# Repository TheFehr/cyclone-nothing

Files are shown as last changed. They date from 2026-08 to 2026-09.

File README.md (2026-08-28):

# cyclone-nothing

Parametric 3D-printable phone holder that mounts a Nothing Phone 2 onto a GameSir Cyclone 2 controller — connector plate, diagonal arm, print-in-place swivel pivot, and a self-centering screw-adjustable clamp.

**[Open the live customizer / STL export →](https://thefehr.github.io/cyclone-nothing/)**
**[Read the assembly guide →](https://thefehr.github.io/cyclone-nothing/assembly_guide.html)**

## What it does

- Snap-fit connector plate slides into the controller's own USB-C accessory port — no glue, no screws, reverse-engineered from a real controller.
- A tilted arm carries a print-in-place swivel pivot, so the clamp rotates 90° between portrait (handheld console emulation) and landscape (x64 emulation — also works for PC streaming) orientations without removing the phone.
- The clamp is a screw-adjustable, car-mount-style claw grip on the phone's short edges — screen and back stay fully exposed. A dual-handed printed leadscrew draws both claws in together and keeps the phone centered at any width.
- **No metal anywhere.** Every joint is either a real printed helical thread or a plain friction-fit pin cut from your own printer filament, glued in place. No screws, nuts, or hardware to source.

## Print + assemble

Nine independent print jobs, no combined prints, no captured/impossible-to-assemble joints — see the [assembly guide](https://thefehr.github.io/cyclone-nothing/assembly_guide.html) for the parts list, hardware (4 filament pins + CA glue), and the exact build order (some joints can only close in one sequence).

Verified STL exports for the current design live in [`stl/`](stl/); the [live customizer](https://thefehr.github.io/cyclone-nothing/) lets you tweak any dimension (screw diameter, rail length, clamp reach, pivot tilt, etc.) and export fresh STLs for your own printer/tolerances.

## Repo layout

- `phone_holder.scad` — the parametric design, annotated with OpenSCAD Customizer comments (drives the live web form automatically).
- `lib/threads.scad` — [rcolyer/threads-scad](https://github.com/rcolyer/threads-scad) (CC0), used for the printed leadscrew/nut threads.
- `stl/` — current verified STL export of all 9 parts.
- `reference/` — measurements/reference meshes the connector plate was reverse-engineered from.
- `index.html` / `worker-shim.js` — the live in-browser preview, built on [openscad-customizer-web](https://github.com/TheFehr/openscad-customizer-web).
- `assembly_guide.html` — step-by-step build guide.

## License

[CC BY 4.0](https://creativecommons.org/licenses/by/4.0/)

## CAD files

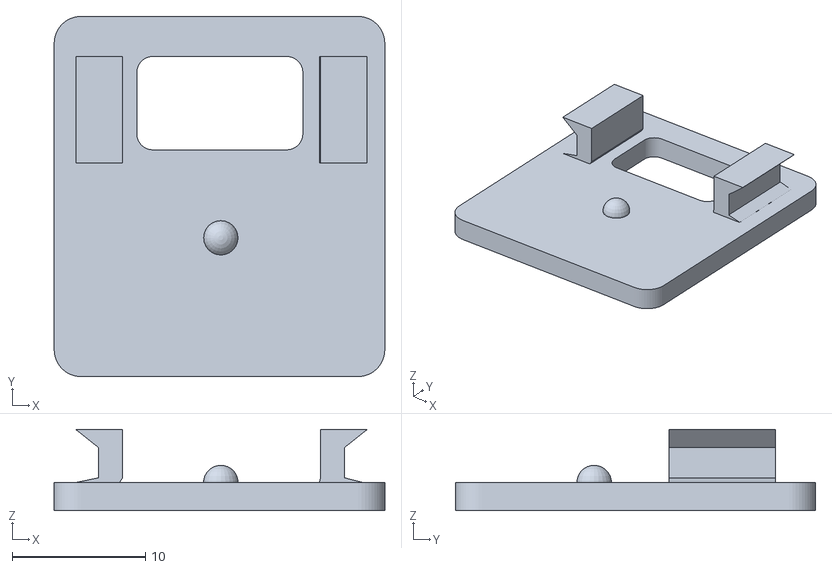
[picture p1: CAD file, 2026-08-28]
connector_plate_4mm.stl
24.8 x 27.0 x 6.11

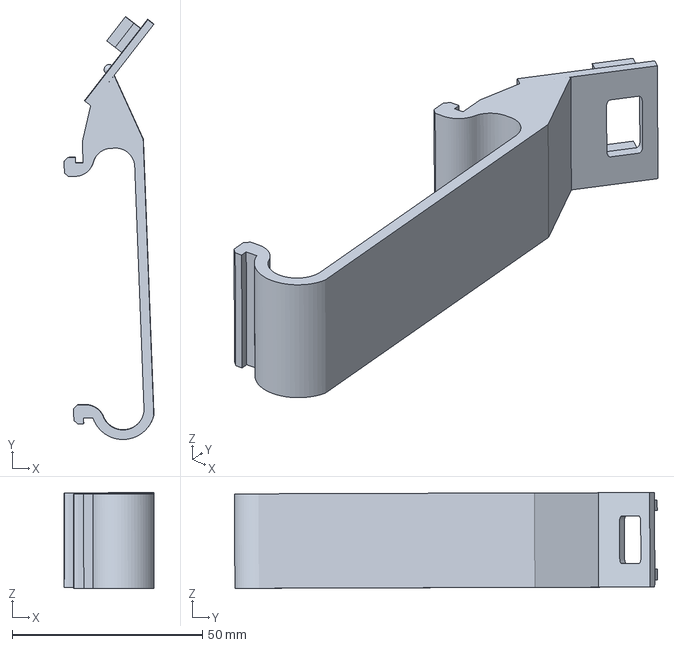
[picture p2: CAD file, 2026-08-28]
reference/Gamesir_iPhone_XS_cover_support.3mf
23.6 x 111.0 x 25.2 mm

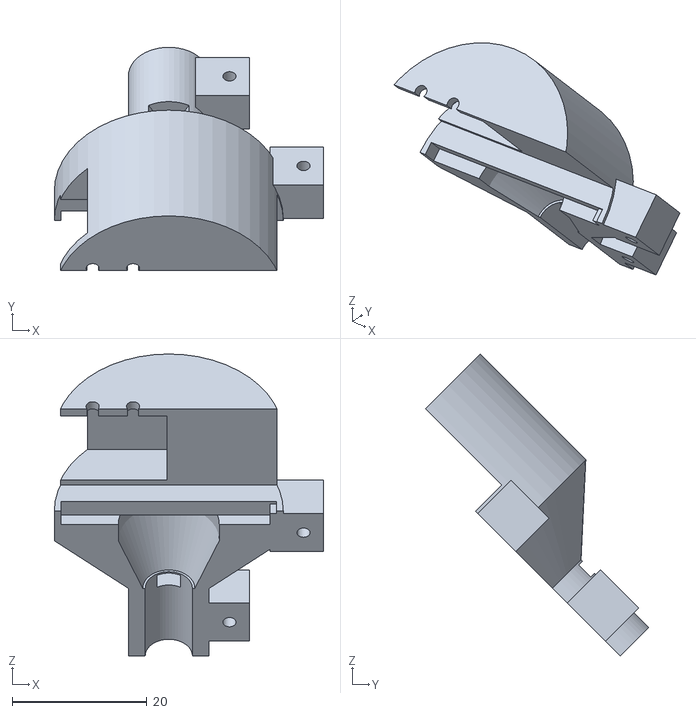
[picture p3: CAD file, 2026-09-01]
stl/collar_bottom.stl
40.0 x 33.2 x 44.8

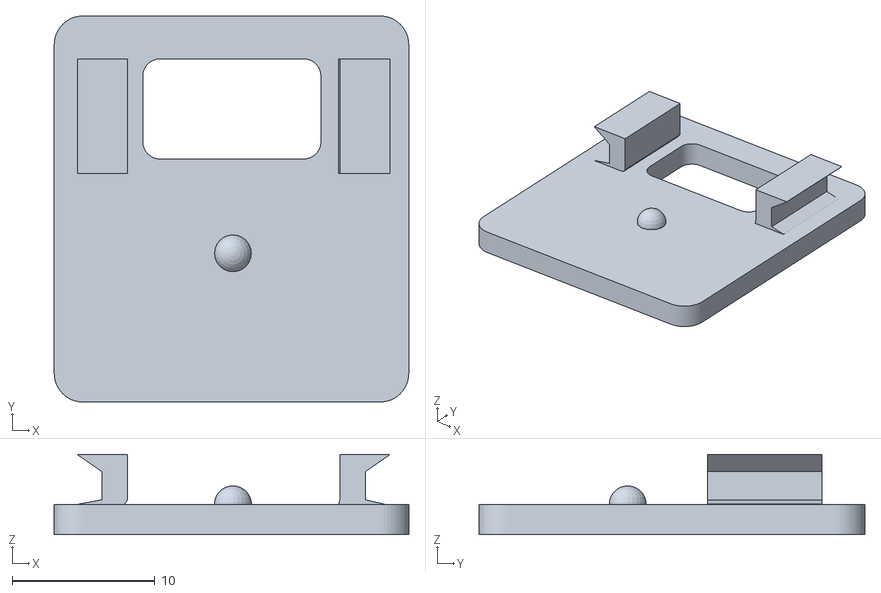
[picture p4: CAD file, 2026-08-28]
connector_plate.stl
24.8 x 27.0 x 5.61

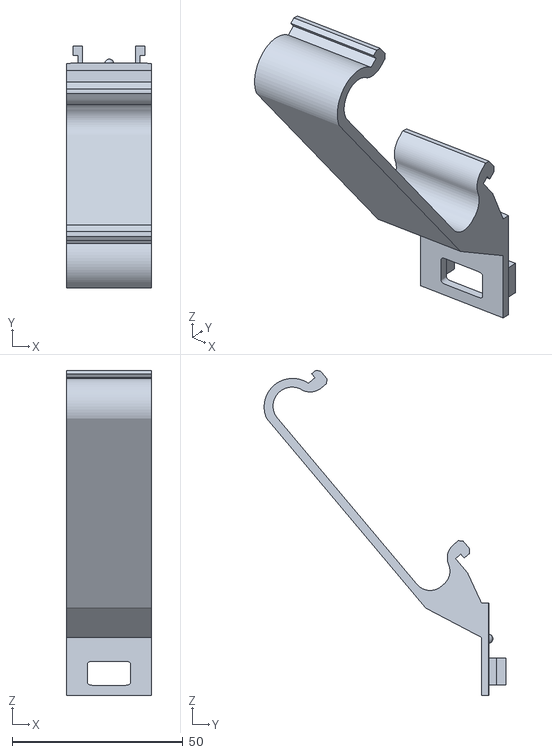
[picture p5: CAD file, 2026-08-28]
reference/iphone_xs_cover_support.stl
24.8 x 70.7 x 95.1

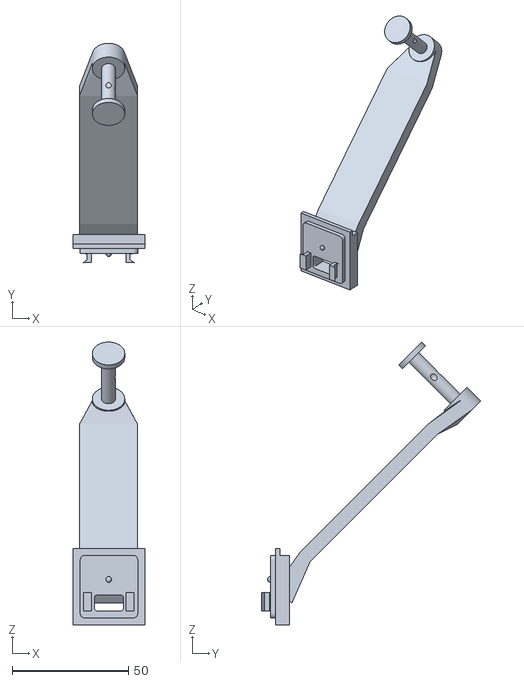
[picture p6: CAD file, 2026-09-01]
stl/base.stl
30.8 x 94.5 x 121.9

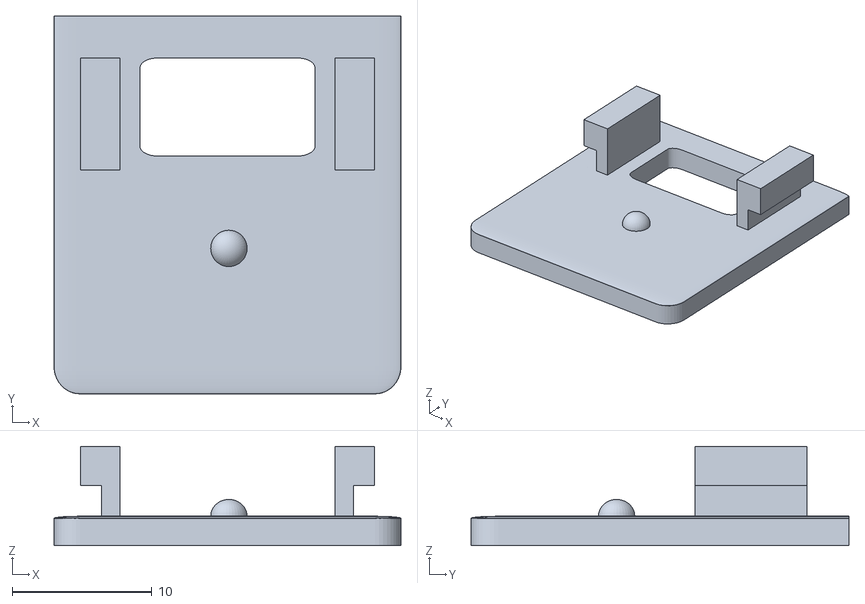
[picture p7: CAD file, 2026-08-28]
reference/connector_only.stl
24.8 x 27.0 x 7.11

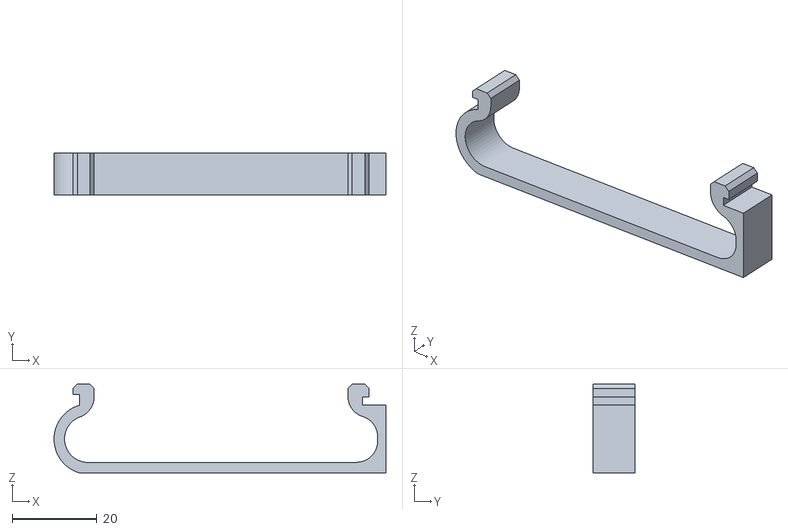
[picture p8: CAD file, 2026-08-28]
reference/size_check_thin.stl
78.5 x 10.0 x 21.0

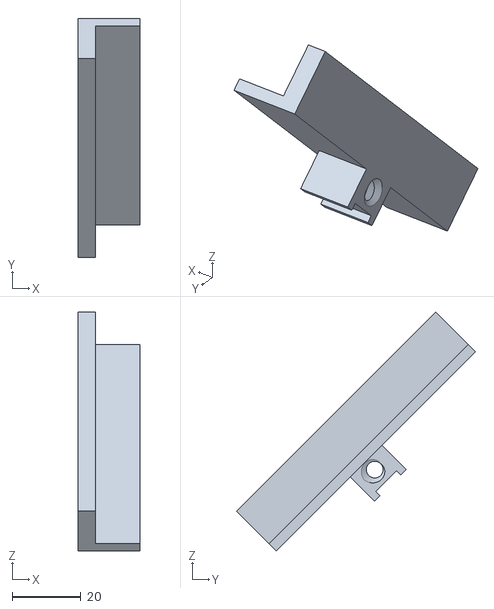
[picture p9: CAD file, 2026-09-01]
stl/clamp_claw_left.stl
18.0 x 69.6 x 69.6

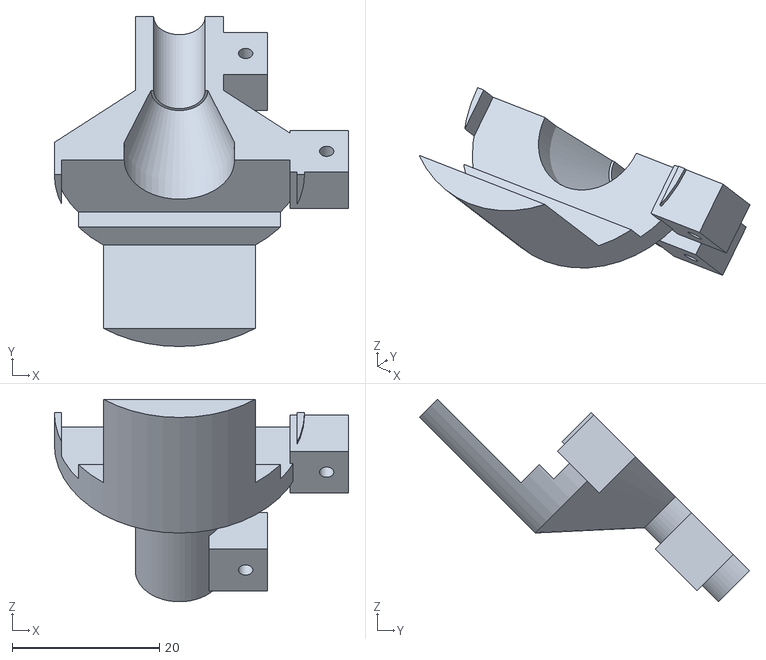
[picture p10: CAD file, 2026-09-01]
stl/collar_top.stl
40.0 x 44.8 x 27.5

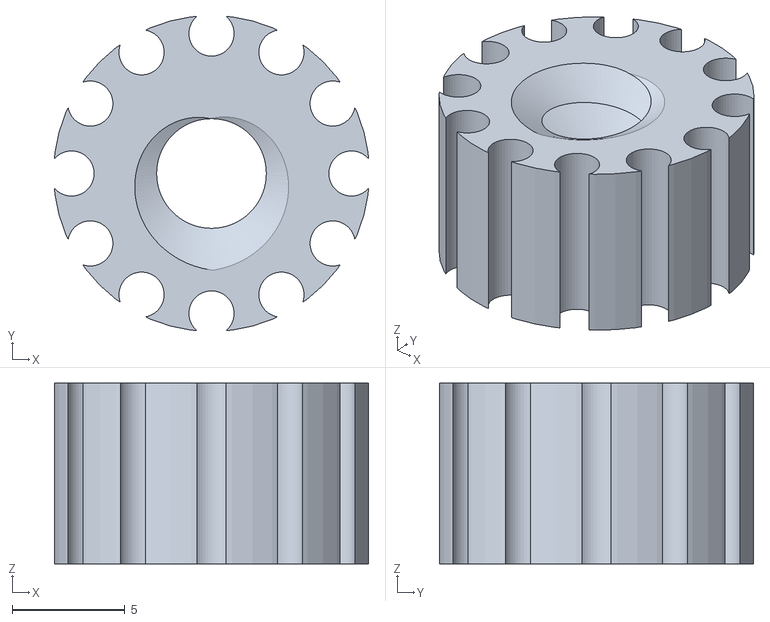
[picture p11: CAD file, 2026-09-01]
stl/knob.stl
13.9 x 13.9 x 8.00

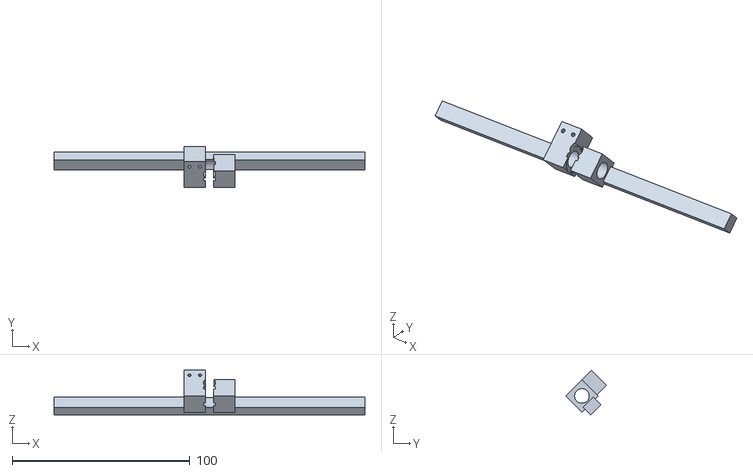
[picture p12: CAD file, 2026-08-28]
stl/clamp_center.stl
175.0 x 23.0 x 25.1

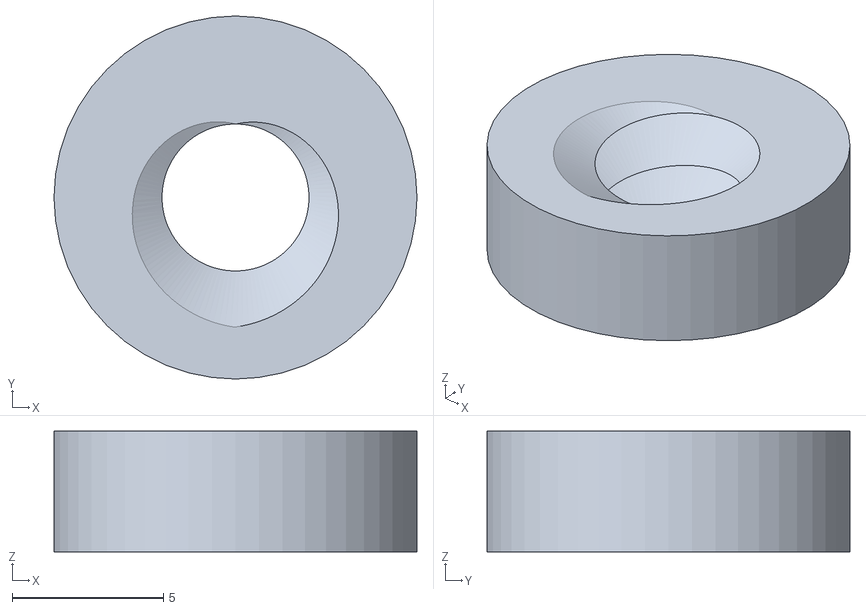
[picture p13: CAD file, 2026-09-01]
stl/flange_nut.stl
12.0 x 12.0 x 4.00

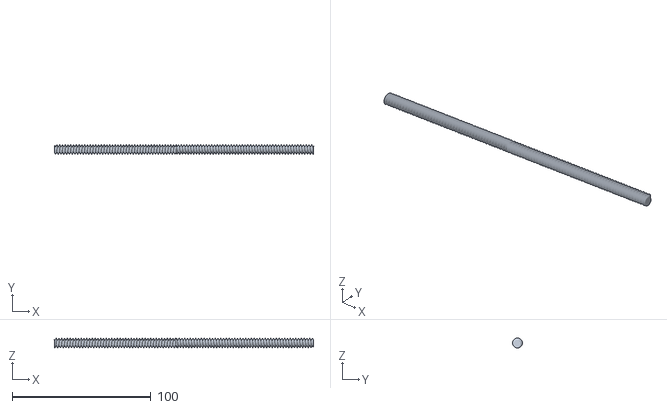
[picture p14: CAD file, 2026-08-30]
stl/screw.stl
186.5 x 7.10 x 7.10

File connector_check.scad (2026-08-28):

bulk_margin=3; bulk_depth=6;
module connector() { rotate([90,0,0]) translate([5.3,-1,2.55]) import("reference/connector_only.stl"); }
module usb_slot_clearance() { translate([-7.5,-3.55,-17.9]) cube([12.7, 3.55+bulk_depth+10, 8.6]); }
module connector_bulk() { difference() { translate([-12.4-bulk_margin, 3.55, -27-bulk_margin]) cube([24.8+2*bulk_margin, bulk_depth, 27+2*bulk_margin]); usb_slot_clearance(); } }
connector();
color("orange",0.6) connector_bulk();

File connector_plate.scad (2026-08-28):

// Standalone connector plate -- the piece that slides into the GameSir
// Cyclone-family controller's mount. Rebuilt natively in OpenSCAD from
// measurements taken off a real, watertight reference mesh
// (reference/connector_only.stl), rather than imported as an opaque mesh,
// so it can be freely extended/modified later without guessing what's
// safe to touch.
//
// Tab-clip size/position/profile, the plate footprint, and the USB-C slot
// are measured to match the reference mesh (these mate with real
// hardware); the corner fillets and the small alignment nub are close
// visual approximations, not exact -- they carry no mechanical function.
//
// The tabs are NOT plain posts -- they're snap-fit barbs: a base flush
// with the plate surface (no riser gap), blending immediately into a
// constant-width neck that slides through the controller's narrow lower
// opening, then a head that flares out in the wider pocket beyond.
//
// Print flat as-is: bottom face on the bed, tabs pointing up, no supports.

plate_w = 24.8; plate_l = 27; plate_t = 2.11; plate_corner_r = 2;
tab_y = -10.0; tab_l = 8.0;

// Depth budget: base to head tip, starting flush at the plate surface
// (Z = plate_top_z) -- confirmed by hand-sketch (option D) that the neck
// must start with zero gap/recess below it, not sit atop a tall separate
// base riser like the first cut did.
plate_top_z = -4.0; plate_bottom_z = -6.11;
tab_z0 = plate_top_z;
// Depth budget arrived at through printed test-fit iteration (8mm guessed
// -> 4.5mm measured -> 3.5mm, still ~1mm too deep -> 4mm confirmed best
// via an A/B print test against a 3.5mm variant).
tab_base_blend_h = 0.34; // short transition from the wide base footprint to the neck, right at the plate surface
tab_z_neck_top = tab_z0 + 2.63; // neck runs most of the depth budget
tab_z1 = tab_z0 + 4.0; // full measured depth budget, head tip

// Neck inner-gap measured directly off the real controller with calipers
// (14.85mm, facing edges) -- center-to-center = 14.85 + neck_w = 16.65mm.
// base_x (the structural bond to the plate) stays at the reference mesh's
// original position; only neck/head -- the part that actually engages the
// controller -- are repositioned, preserving the previous midpoint.
tab1_base_x = -16.0; tab1_neck_x = -14.375;
tab2_base_x = 2.2; tab2_neck_x = 2.275;
// Each head flares away from the slot (not toward it) to avoid colliding
// with it now that the necks sit closer to center: tab1 keeps its neck's
// RIGHT edge flush and widens left; tab2 keeps its neck's LEFT edge flush
// and widens right.
tab1_head_x = tab1_neck_x - 1.7; // = tab1_neck_x + tab_neck_w - tab_head_w, right-edge flush
tab2_head_x = tab2_neck_x; // left-edge flush

// neck_w capped just under 1.85mm (the real controller's lower-opening
// width, measured) since the neck has to slide through it; head_w capped
// just under 3.6mm (measured max for the wider pocket beyond) -- both
// maximized within those limits for retention strength.
tab_base_w = 3.2; tab_neck_w = 1.8; tab_head_w = 3.5;
slot_x = -11.5; slot_y = -9; slot_w = 12.45; slot_h = 7; slot_corner_r = 1.2;
nub_x = -5.2; nub_y = -15.6; nub_r = 1.3;

$fn = 48;

module tab_clip(base_x, neck_x, head_x) {
    hull() {
        translate([base_x, tab_y, tab_z0]) cube([tab_base_w, tab_l, 0.02]);
        translate([neck_x, tab_y, tab_z0 + tab_base_blend_h]) cube([tab_neck_w, tab_l, 0.02]);
    }
    translate([neck_x, tab_y, tab_z0 + tab_base_blend_h])
        cube([tab_neck_w, tab_l, tab_z_neck_top - (tab_z0 + tab_base_blend_h)]);
    hull() {
        translate([neck_x, tab_y, tab_z_neck_top]) cube([tab_neck_w, tab_l, 0.02]);
        translate([head_x, tab_y, tab_z1 - 0.02]) cube([tab_head_w, tab_l, 0.02]);
    }
}

module connector_plate_native() {
    difference() {
        union() {
            translate([-17.7, -26, plate_bottom_z])
                linear_extrude(plate_t)
                    hull()
                        for (x = [plate_corner_r, plate_w - plate_corner_r])
                            for (y = [plate_corner_r, plate_l - plate_corner_r])
                                translate([x, y]) circle(r = plate_corner_r);
            tab_clip(tab1_base_x, tab1_neck_x, tab1_head_x);
            tab_clip(tab2_base_x, tab2_neck_x, tab2_head_x);
            translate([nub_x, nub_y, plate_top_z]) sphere(r = nub_r, $fn = 24);
        }
        translate([0, 0, plate_bottom_z - 1])
            linear_extrude(plate_t + 2)
                hull()
                    for (x = [slot_x + slot_corner_r, slot_x + slot_w - slot_corner_r])
                        for (y = [slot_y + slot_corner_r, slot_y + slot_h - slot_corner_r])
                            translate([x, y]) circle(r = slot_corner_r);
    }
}

connector_plate_native();

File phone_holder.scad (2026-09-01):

// Phone holder arm for a GameSir Cyclone-family controller + Nothing Phone 2.
//
// Layout: [connector, bulked for strength, USB-C slot left open] --diagonal
// arm (angle customizable)--> [print-in-place rotating pivot] --> [clamp
// running along the phone's LONG edge].
//
// The pivot's rotation axis is perpendicular to the phone's flat face, so
// spinning the clamp end 90 degrees swaps portrait (DS emulation) <->
// landscape (PC emulation) while the phone stays flat-facing the same way.
// It's a single printed-in-place pin+collar (no bolt/nut, no second print)
// -- print with the model rotated so Y is vertical on the bed, so the
// pin/collar layers form clean concentric circles instead of needing to
// bridge the clearance gap.
//
// Base geometry (connector_only.stl) is reverse-engineered from a
// Thingiverse remix (thing:6765266, nikopla / HaraldVI, CC BY), kept
// byte-for-byte since it has to mate with real hardware.
//
// The phone clamp is screw-adjustable, car/bike-mount claw style: a small
// hook claw at each end of a rail grips only the phone's short top/bottom
// edges -- screen and back stay fully exposed. One claw is fixed, the
// other rides a printed leadscrew (real threads, rcolyer/threads-scad,
// CC0) that runs along the phone's long axis -- no metal hardware
// anywhere in this design.

use <lib/threads.scad>

/* [Render] */

// Which piece to show/export. "full" is an assembled preview only -- the
// pivot pin/collar, the two claws, and the leadscrew are separate, unfused
// bodies (by design -- print-in-place pivot, screw-adjustable clamp), so
// it isn't watertight/printable as a single part.
render_part = "connector"; // [connector:Connector plate only — reference only; base.stl already includes it,base:Connector + arm + pivot pin (print this),clamp_center:Rail + both bearing bosses — no collar (print this),collar_top:Pivot collar top half — screws onto collar_bottom around the pin (print this),collar_bottom:Pivot collar bottom half (print this),flange_nut:Screw retention flange — threads onto the screw's center then glued (print this),TEST_flange_fit:Quick fit test — flange_nut + a short thread stub — print this first to check thread_tolerance before the full screw,TEST_claw_fit:Quick fit test — full-length claw thread bore (no lip/wall) + a matching stub — print this first to check thread_tolerance before a full claw,TEST_pivot_detent:Quick fit test — short shaft + short tube with the pivot detent — print this first to tune the click force before a full pin/collar,clamp_claw_right:Right claw — right-hand thread (print this),clamp_claw_left:Left claw — left-hand thread (print this),screw:Dual-thread leadscrew — no flange or knob (print this),knob:Turning knob — threads onto the screw's tip then glued (print this),full:Full assembly (preview only)]

/* [Connector] */

// Extra material added around the connector base for strength (the USB-C
// slot is always kept clear regardless of this value)
bulk_margin = 3; // [0:0.5:8]

// How far the bulk pad extends outward before the arm begins
bulk_depth = 6; // [2:0.5:15]

/* [Arm] */

// Tilt of the arm away from straight-up, toward the phone
arm_angle = 45; // [0:1:60]

// Arm length along that diagonal -- driven by DS/portrait-mode clearance,
// not looks. Short-edge grip (claws on the phone's 162mm length, naturally
// symmetric on X) plus the now-symmetric width grip (Y) gives a worst-case
// corner at sqrt(81^2 + 38.2^2) = ~89.6mm from the axis. 110 gives ~96.4mm
// of clearance against the reinforced connector pad (verified via the
// same closest-point-to-bbox check used throughout), a margin over the
// 89.6mm minimum.
arm_length = 110; // [20:1:220]

// Cross-section at the pivot end
arm_thickness = 6; // [2:0.5:12]
arm_width = 25; // [20:0.5:30]

// Cross-section at the connector end -- thicker on purpose: this is a
// cantilever fixed at the connector and loaded at the pivot end, so
// bending stress is highest right here, not at the tip
arm_base_thickness = 10; // [4:0.5:18]
arm_base_width = 24.8; // [20:0.5:30]

// How far the gusset at each end blends into the standard arm
// cross-section before running the rest of arm_length at full thickness
arm_gusset_len = 16; // [5:1:40]

/* [Pivot] */

// Print-in-place: rotation axis runs perpendicular to the phone's face.
// Print with this axis vertical on the bed for a clean result.
pivot_shaft_dia = 6; // [4:0.5:12]
pivot_shaft_len = 30; // [16:1:60]
pivot_flange_dia = 14; // [8:0.5:24]
pivot_flange_h = 2.4; // [1.2:0.2:5]
pivot_collar_dia = 12; // [8:0.5:22]
pivot_clearance = 0.5; // [0.2:0.05:1]

// Detent so the pivot actually HOLDS portrait/landscape instead of free-
// spinning under the phone's own weight (real print feedback, 2026-09-01
// -- pivot_clearance above is a pure running-clearance fit, nothing in
// this design ever created any resistance at all). A single flexible tab
// on the collar's own bearing tube, with a small bump on its inner face,
// riding on the shaft -- pushed outward (flexed) everywhere except at two
// shallow dimples cut into the shaft 90deg apart, where it relaxes and
// "clicks" in. No fixed relationship between the collar's own rotation
// reference and either dimple is needed -- the collar isn't keyed to the
// pin at assembly (you close the clamshell around the shaft at whatever
// starting angle), so both detent positions are reached identically by a
// 90deg swing regardless of where you started, the same swing that
// already swaps portrait/landscape.
//
// UNTESTED. FDM cantilever spring force from CAD alone is notoriously
// unreliable -- wall thickness accuracy, layer adhesion direction, and
// material all move it a lot. Print TEST_pivot_detent (a short shaft-and-
// tab coupon) and adjust detent_bump_h/detent_tab_wall against it before
// committing to a full pin+collar reprint.
detent_bump_h = 0.6; // [0.1:0.05:0.8] how far the tab's rest position reaches past the shaft's plain surface -- also the dimples' depth. Bumped from 0.4 (2026-09-02): real TEST_pivot_detent print had too little resistance/held too loosely at 0.4. Re-test with the coupon again before committing to a full pin+collar reprint.
detent_tab_wall = 1.2; // [0.6:0.1:2.5] radial thickness of the flexible tab -- thinner flexes more easily but risks snapping instead of springing
detent_tab_arc = 60; // [30:5:100] degrees of arc the tab spans -- its flex length

// How far the collar extends PAST the shaft's far flange before the rail/
// claw assembly attaches, measured from where the flange-clearing cap
// ends. The claws need to reach all the way to the true axis line (X=0,
// Y=0) to grip the phone centered on BOTH axes -- but at the shaft's own
// depth, that exact spot is solid collar material. This pushes the
// attachment point further along the axis (further from the connector,
// "toward the user") into empty space where nothing blocks X=0,Y=0.
//
// Trimmed down from an earlier, more generous 30 once a structural check
// showed the extra rod thickness wasn't needed (bending stress from the
// phone's static weight is ~25x under typical FDM strength regardless).
// But it can't go BELOW ~20.2: at that point the rail creeps back far
// enough to overlap the FAR FLANGE's own Z-range (a separate constraint
// from the rod-length one) -- caught via the full rotation-sweep check,
// which showed a constant collision at every angle (a dead giveaway it
// was a static Z-overlap, not an actual rotational sweep problem). 24
// keeps a few mm of margin over that floor.
pivot_standoff = 24; // [21:1:60]

// Extra tilt of the pivot axis, on top of the base -90 degrees (which
// would face the clamp straight back down the arm at the controller).
// Needed for two reasons: (1) so the phone's screen faces the user
// instead of pointing down at their hands on the controller, and (2) so
// the clamp/rail clears the arm and controller body as it swings between
// DS/portrait and PC/landscape instead of crashing into them mid-rotation.
// ~135 was confirmed correct via a render sweep (0/45/90/135/180/-45)
// against where the screen should face -- re-verify with a render if the
// arm_angle or connector orientation changes materially.
pivot_tilt = 135; // [0:1:180]

/* [Clamp] */

// Total rail length, along the phone's LONG axis -- needs to cover the
// phone's height (162mm) plus adjustment travel
rail_length = 175; // [100:1:250]

// Distance from the rail's center (X=0, where the pivot attaches) to each
// claw. Both claws sit at +-claw_offset -- symmetric, so the phone stays
// centered on the pivot on the LENGTH axis at any grip width. Default
// targets a ~162mm grip span to match the Nothing Phone 2's height.
claw_offset = 81; // [20:1:85]

// Width of each claw along the rail axis
claw_width = 18; // [10:1:30]
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

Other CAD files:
stl/clamp_claw_right.stl

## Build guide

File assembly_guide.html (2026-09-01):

# Pivot Mount Assembly

Nine printed parts. No metal anywhere — every joint is either a printed thread or a friction-fit pin cut from the same filament you printed with, plus CA glue. Follow the sequence — some joints can only be closed in this order.

cyclone‑nothing / phone_holder.scad
rev 2026‑08‑30
9 parts · 4 filament pins · 0 metal

## 01Parts manifest

Print all nine before starting assembly. Each is a standalone job — nothing here needs to be printed in the same session as anything else.

Base

Base

base.stl

Connector, arm, and the fixed pivot pin — one solid piece.

qty 1

Rail with both bearing bosses

Rail & bosses

clamp_center.stl

The long rail with both bearing bosses fixed in place, plus the rod-connect shelf.

qty 1

Collar top half

Collar — top half

collar_top.stl

Clamshell half. Closes around the pin from above.

qty 1

Collar bottom half

Collar — bottom half

collar_bottom.stl

Carries the full standoff rod and its two rail pin holes.

qty 1

Flange nut

Flange nut

flange_nut.stl

Threads onto the leadscrew's own thread inside the gap, then glued. Captures the screw axially so it can spin but not slide.

qty 1

Leadscrew

Leadscrew

screw.stl

Right- and left-hand thread from center; right-hand thread runs all the way to the tip.

qty 1

Knob

Knob

knob.stl

Threads onto the screw's tip, then glued — last part installed.

qty 1

Right claw

Claw — right

clamp_claw_right.stl

Right-hand thread bore. Threads onto the +X half.

qty 1

Left claw

Claw — left

clamp_claw_left.stl

Mirrored thread bore. Threads onto the −X half.

qty 1

Hardware 4× ~15mm length of your own 1.75mm printer filament, cut with flush cutters, used as friction-fit pins · small drop of CA or epoxy at the flange nut, both pin joints, and the knob · no metal anywhere in this build

## 02Build sequence

Two sub-assemblies come together independently, then join at the very end. Steps 1–3 build the clamp; step 4 builds the pivot; steps 5–6 join them and finish.

Flange nut held in the open gap between the two bosses, no screw yet

1

### Start the leadscrew into the near boss

clamp_center.stl + screw.stl

The leadscrew's two ends aren't interchangeable here: flange_nut only threads onto the left-hand-thread end. Feed that end into its matching boss and turn it in just until a little thread pokes through into the open gap. (The other end is right-hand thread all the way to its tip — wrong handedness for this nut, so it never comes into it.)

Leadscrew threaded all the way through the flange nut and both bosses

2

### Thread the flange nut on as you turn it in

+ flange_nut.stl · CA glue

Hold flange_nut right at the gap where the thread is just starting to emerge — it catches immediately, since that thread is already the same handedness as the nut. Keep turning the leadscrew in the same direction: the nut climbs onto it and seats itself within the gap after a few turns, then just rides there while you keep feeding the rest of the leadscrew through — through the nut's own bore and on through the far boss — until it's fully seated, parallel with the rail underneath. Run a small bead of CA glue around the nut once everything's seated so it can't work itself loose.

Check: once the glue sets, spin the leadscrew by hand. It should turn smoothly with no drag or axial play before you continue. If feeding the last stretch through the nut feels tight or binds, stop and let us know — that specific step hasn't been physically confirmed yet.

Both claws threaded onto the screw

3

### Thread on the claws

+ clamp_claw_right.stl + clamp_claw_left.stl

Rotate clamp_claw_right onto the screw's +X (right-hand thread) end, and clamp_claw_left onto the −X (left-hand thread) end, threading each in from the tip toward the center. Because the threads are opposite-handed, turning the leadscrew one way draws both claws in together and centers the grip automatically.

Base pin with both collar halves closing around it

4

### Close the collar around the pin

base.stl + collar_top.stl + collar_bottom.stl · 2 filament pins

Set base's pin down and bring collar_top and collar_bottom together around it — the two halves meet along the pin's own axis. Push a ~15mm length of 1.75mm filament through each of the two tabs' aligned holes to close the clamshell, and add a small drop of CA glue at each so they can't work loose. Confirm the collar rotates with a steady, even resistance the whole way around, and clicks noticeably at two points 90° apart (the detent) — not free-spinning, and not so stiff you can't turn it by hand. It's this resistance that holds the phone in portrait/landscape instead of it falling under its own weight.

Collar and clamp sub-assembly joined

5

### Join the two sub‑assemblies

step 4 result + step 3 result · the last 2 filament pins

Push your last 2 filament pins into the two holes at collar_bottom's standoff rod tip, leaving them protruding slightly. Bring the clamp sub‑assembly (from step 3) up to meet the rod, aligning the connect shelf on clamp_center so the protruding pin ends slide into its matching holes as the two faces come together — like a standard dowel joint. Add a small drop of CA glue at each pin once seated. This is the joint that makes the rail and claws actually rotate with the collar — everything downstream of it now turns together as one unit.

Finished assembly with knob and phone outline

6

### Thread on the knob

+ knob.stl

Thread knob onto the screw's tip (right-hand thread, same direction as the right claw) and turn it until it seats flush against the right claw's outward wall. Put a small drop of CA or epoxy at the seam once seated — the thread engagement carries the turning torque, the glue just keeps it from working loose. Give the glue its full cure time before using the knob to adjust the clamp.

Done: the phone's short edges seat in the two claws, centered on the true pivot axis in both length and width. Turn the knob to open or close the grip; rotate the whole clamp 90° on the collar to swap portrait and landscape.

cyclone‑nothing phone_holder.scad

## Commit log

2026-08-28 Initial commit: phone_holder pivot mount design, STLs, and assembly guide
    Nine-part, fully modular, metal-free design (printed threads + 1.75mm
    filament friction-fit pins) for mounting a Nothing Phone 2 onto a
    GameSir Cyclone 2 controller. Includes the parametric OpenSCAD source,
    current verified STL exports, and a step-by-step HTML assembly guide.
    [Gamesir_iPhone_XS_cover_support.3mf, base.stl, clamp_center.stl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]
2026-08-28 Set up GitHub Pages: live customizer + assembly guide
    Matches the pattern used by earpad-adapter and openscad-customizer-web
    itself: preview.html -> index.html (served at the Pages root), a
    minimal actions/deploy-pages workflow, .nojekyll, and .gitattributes
    for sane diffs on the .scad source. Cross-linked index.html and
    assembly_guide.html so either page reaches the other. Added a README
    pointing at both published pages.
2026-08-28 Fix connector's misleading print label, add pregen STL fast-path
    The connector-only render_part was labeled "(print this)" even though
    base.stl already includes it -- printing it separately is redundant,
    not a real 9th part. Clarified the Customizer dropdown label.
    index.html now uses openscad-customizer-web's lower-level building
    blocks (parseCustomizer/buildForm/Viewer + a raw worker) instead of
    the OpenScadPreview all-in-one class, specifically to support loading
    a pre-rendered STL from stl/ instead of a live WASM render whenever
    render_part is one of the 9 real print jobs and every other parameter
    is still at its Customizer default -- same pattern ttrpg-prints uses.
    Any parameter edit a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
    [phone_holder.scad]
2026-08-28 Remove commas from render_part option labels (broke the dropdown)
    openscad-customizer-web's Customizer parser splits [value:Label,...]
    on every top-level comma with no escaping (confirmed in its own
    source: splitOptions() is a plain inner.split(',')) -- any comma
    inside a label silently fractures it into extra bogus options. Nearly
    every existing label had one ("Rail + both bearing bosses, no collar",
    "Dual-thread leadscrew, no flange, no knob", etc.), not just the
    connector label from the previous commit, which made it visibly worse.
    Rewrote every label comma-free (em dash/semicolon instead). Verified
    against the actual parser logic and live in a headless browser: the
    dropdown now renders e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
    [phone_holder.scad]
2026-08-28 Fix flange_nut() not threading onto the screw at all (real print failure)
    flange_nut()'s ScrewHole() call never passed tolerance = thread_tolerance,
    silently falling back to threads.scad's own library default (0.4mm)
    instead -- every other threaded cut on this same clamp_screw_dia/pitch
    (the claws) already passes thread_tolerance (0.8mm) explicitly. That
    inconsistency is the direct cause of the screw not engaging at all.
    No value here has actually been print-confirmed for THIS thread's own
    engagement specifically -- thread_tolerance=0.8 was bumped after a real
    print issue, but that issue was the screw seizing in the plain bearing-
    boss bore, not a thread fit. This fix makes flange_nut() con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
    [flange_nut.stl, phone_holder.scad]
2026-08-28 Document screw print orientation: lying flat, not standing
    At the default rail_length the screw is ~171mm long at 7mm diameter
    (~25:1 aspect ratio) -- standing it vertically isn't realistic on
    basically any printer. The test piece's thread stub prints vertically
    fine because it's short (~20mm); that's not guidance for the full
    screw. User correctly flagged that my earlier "prints in its natural
    orientation (axis vertical)" note for the test piece could be misread
    as applying to the real screw too.
    [phone_holder.scad]
2026-08-28 Make flange_nut left-handed -- the right-handed version was physically impossible
    Real print: the screw would not thread into flange_nut at all, even
    after the earlier tolerance fix. The actual problem wasn't tolerance --
    it was that flange_nut was cut RIGHT-handed, matching the geometric
    right-hand thread half. A closed-ring nut can only get onto a one-piece
    continuous shaft by threading in from a genuinely free end and
    traveling along it, and neither of the screw's two free ends works for
    a right-handed nut: the far left-hand tip is the wrong handedness (a
    real print confirmed it won't even catch), and the peg end is blocked
    outright. There was no reachable free end anywhere near where the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
    [flange_nut.stl, phone_holder.scad, screw.stl]
2026-08-28 Redesign collar_bottom/collar_top: fix overhangs and a near-zero wall
    Lengthen collar_taper_len 3mm->10mm -- the old taper grew the collar's
    radius by 8mm in only 3mm of height (~69deg from vertical), well past
    self-supporting.
    Restore a plain Y=0 clamshell split through the whole rod, including the
    standoff. It used to be left entirely whole and fused onto one half
    because a plain split fragmented it into 3 pieces -- but that was true at
    an old clamp_screw_dia=5; re-checked via connected-components against the
    current parameters and both halves now come back as a single piece each.
    The old workaround was stale, and it was the actual cause of the overhang
    complaint: a half-open tube abruptl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
    [collar_bottom.stl, collar_top.stl, phone_holder.scad]
2026-08-30 Fix right claw: its own peg physically blocks it from ever threading on
    The knob's anti-rotation peg (peg_size=4, diagonal 5.66mm) sat right in
    the path the right claw must slide through to reach its thread from the
    open +X tip. The old comment waved this through as "cosmetic" based on a
    connected-components check on the already-assembled model -- but that
    only proves the meshes are watertight where they touch, not that the peg
    can actually be slid through the claw's threaded bore to get there.
    It can't: the claw's internal thread (cut by ScrewHole()'s cutter) has a
    ~4.61mm minor diameter, half a mm narrower than the peg's 5.66mm diagonal.
    Confirmed via an actual difference()-against-the-re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
    [collar_bottom.stl, collar_top.stl, knob.stl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]
2026-08-30 Replace knob's anti-rotation peg with a real threaded joint
    Shrinking the peg to 2.5mm (previous commit) wasn't actually enough: the
    2mm plain stub bridging the thread's end to the peg was ALSO a real
    obstruction, independent of the peg. Confirmed the same way -- a plain
    clamp_screw_dia-wide shaft, swept across a full pitch of phase against
    the claw's own thread cutter, leaves real (2000+ facet) leftover material
    at every phase. A claw's internal thread ridge can only trace a helix
    that's already there (the screw's own matching groove); it can't slide
    past ANY plain, non-threaded material close to clamp_screw_dia, peg or
    no peg. The right claw still could not have been threaded on.
    Root fix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
    [knob.stl, phone_holder.scad, screw.stl]
2026-08-30 Bump assembly guide rev date to 2026-08-30
    Content changed today (knob/screw peg-to-thread redesign, wording
    updates) but the header's rev stamp was still showing the previous
    edit's date.
2026-09-01 Bump thread_tolerance for the claws, add a pivot detent
    Two real print-failure reports:
    1. Claws bound up on the screw even printed correctly (bore axis
    vertical), getting progressively tighter over the screw's travel through
    the full slider_len engagement rather than failing at the tip -- an
    overhang/bridging analysis on the bore itself didn't clearly indict
    orientation, and "gets tighter over distance" points at accumulated print
    imperfection eating into the margin over a long thread run, which is what
    more radial clearance is for. Bumped thread_tolerance 0.8->1.0 (same
    shared parameter as flange_nut/knob, re-rendered both). Added
    TEST_claw_fit: a full-slider_len thread-bore coupon (skips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
    [base.stl, clamp_claw_left.stl, clamp_claw_right.stl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]
2026-09-01 Fix comma in knob's render_part label, breaking the Customizer dropdown
    Same class of bug as 99ffa09 -- introduced this one myself while
    rewording the label for the threaded-knob redesign ("threads onto the
    screw's tip, then glued"). Verified all 14 option labels now split
    cleanly on comma with no stray ones inside any label text.
    [phone_holder.scad]
2026-09-01 Add a lint check for render_part Customizer label commas
    Comma is the delimiter in render_part's // [key:label,...] Customizer
    comment -- a comma inside a label's own text silently corrupts the
    dropdown. Shipped for real twice (commit 99ffa09, and again earlier
    today in this same file). scripts/check_render_part.py checks that every
    comma-separated segment starts with a real identifier key, and (bonus,
    same line) that every dropdown key has a matching render_part == "..."
    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
2026-09-01 Increase pivot detent engagement (detent_bump_h 0.4->0.6mm)
    Real TEST_pivot_detent print (2026-09-01/02): held too loosely, not
    enough resistance to be useful as a detent. 0.6mm brings the tab-vs-
    shaft interference from ~2.26mm^3 to ~2.97mm^3 (a real, not marginal,
    increase) while the two shaft dimples still remove only ~7% of the
    shaft's cross-sectional area at that Z-band (was ~4%) -- still well
    short of a structural concern.
    Re-verified the same way as the original detent: manifold/NoError and
    single-connected-component on base, collar_bottom, collar_top, and
    TEST_pivot_detent; a wall-thickness re-scan on collar_bottom shows no new
    thin spots (same pre-existing rod-region points as befo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
    [base.stl, collar_bottom.stl, phone_holder.scad]
2026-09-01 TEST_pivot_detent: give the shaft extra length to grip while testing
    Real feedback (2026-09-02): with shaft and tube both at test_len, sliding
    the tube fully on left nothing to hold onto while twisting to test the
    click. Shaft now gets test_shaft_extra (25mm) of bare length past the
    tube's own end -- matches how the real assembly always has spare shaft
    too, since the collar only ever covers part of pivot_shaft_len's 30mm.
    Re-rendered: manifold/NoError, still exactly 2 connected components
    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
    [phone_holder.scad]
